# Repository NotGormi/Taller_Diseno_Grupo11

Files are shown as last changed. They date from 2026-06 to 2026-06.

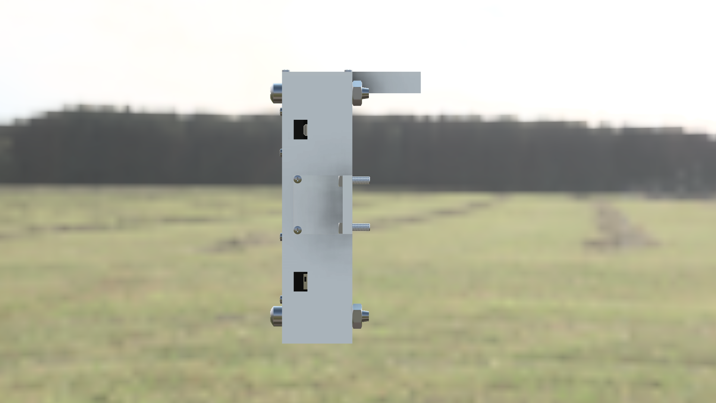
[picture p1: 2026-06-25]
diseno_3d/renders/03_isometrica_lateralD_v3.2.png

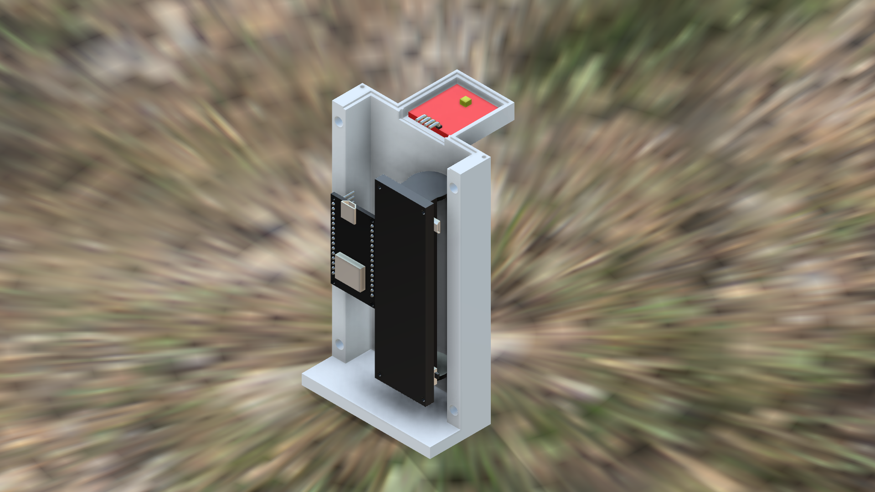
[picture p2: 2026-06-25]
diseno_3d/renders/05_componentes_expuestos_v3.2.png

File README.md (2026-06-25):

### Información del Equipo
- **Integrantes:**
  - Franco Coppellotti - Diseño 3D
  - Daniel Gormaz - Software
  - Vicente Molinos - Hardware
  
- **ODS Seleccionado:** ODS 3: Salud y bienestar
- **Problema a resolver:** Exposición inmedida al sol

### Descripción del Proyecto
Con la medición inmediata de rayos UV, se permite tomar accion para proteger la salud
de los estudiantes.

### Estado del Proyecto
- **Versión actual:** v3.0
- **Última actualización:** 24 de Junio, 2026
- **Estado:** Prototipo final

---

##  Estructura del Repositorio
```
├── hardware/          # Circuitos, esquemas y BOM
    ├── bom/
    ├── esquemas/
    └── fotos/
├── software/          # Código Arduino y librerías
    ├── docs/
    ├── librerias/
    └── src/
├── diseno_3d/        # Modelos Fusion 360 y renders
    ├── fusion360/
    ├── planos/
    └── renders/
├── testing/          # Validación con usuarios
    ├── datos/
    ├── evidencias/
    └── reportes/
├── documentacion/    # Reportes y presentación
    ├── presentacion/
    └── reporte_final/
└── iteraciones/      # Historial de versiones
    ├── iteracion_1/
    ├── iteracion_2/
    .
    .
    .
    └── iteracion_n/
```

---

##  Inicio Rápido

### Requisitos Previos
- Arduino IDE 2.3.8
- Fusion 360

### Instalación
1. Clonar el repositorio
2. Instalar librerías (ver `software/librerias/`)
3. Cargar código en ESP8266

---

##  Checklist de Entrega

### Hardware ✓
- [x] Esquema del circuito (Fritzing/Wokwi)
- [x] BOM completo
- [x] Fotos de alta resolución

### Software ✓
- [x] Código comentado
- [x] Librerías documentadas
- [x] Manual de instalación

### Diseño 3D ✓
- [x] Archivos Fusion 360 (.f3d) con TODOS los componentes
- [x] Renders de alta calidad (1+ ángulos)
- [x] Planos técnicos

### Testing ✓
- [ ] Reporte de testing con usuarios (mín. 5)
- [ ] Evidencias fotográficas/videos
- [ ] Datos cuantitativos

### Documentación ✓
- [x] Reporte final (máx. 15 páginas)
- [x] Presentación (10 min)

---

---

##  Licencia
Este proyecto es desarrollado como parte del curso TEI201 - Facultad de Ingenieria y Ciencias - Universidad Adolfo Ibañez

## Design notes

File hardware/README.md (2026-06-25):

# Hardware - Documentación

## Contenido
Esta carpeta contiene toda la documentación técnica del hardware del proyecto.

### 📁 Carpetas

#### `esquemas/`
Diagramas de circuitos y esquemáticos del sistema

#### `bom/`
Bill of Materials (Lista de materiales)

#### `fotos/`
Fotografías de alta resolución del prototipo ensamblado

---

## Instrucciones de Ensamble

### Componentes Principales
1. [ESP 8266] - Traducir los datos analógicos del sensor y mandarlos a una base de datos
2. [GUVA-S12SD] - Sensor que detecta radiación UV
3. [Shield and Battery 18650] - Alimentación eléctrica al circuito

### Pasos de Ensamblaje
1. Soldar los cables de GND y 3V en el battery shield
2. Afirmar los componentes ESP 8266 y el Shield a la cara posterior del encapsulado con pernos y tuercas
3. Afirmar el piso a la cara delantera del encapsulado con pegamento para plastico
4. Afirmar la cara delantera y posterior con tornillos o pernos y tuercas
5. Afirmar el techo a las dos caras con tornillos
6. Afirmar los enganches laterales a la cara posterior con 2 tornillos en cada enganche
7. Afirmar el encapsulado a una superficie con la ayuda de los 2 tornillos delanteros de los enganches, y la ayuda de 4 tornillos del cuerpo principal si fueron utilizados en el paso 4

### Precauciones
- ⚠️ Al soldar los cables al battery shield procurar que los estaños para cada cable no entren en contacto
- ⚠️ Procurar lijar bien cualquier superficie que sea impresa con soportes por la impresión 3d

---

## Especificaciones Técnicas

**Alimentación:** [3.3V y 3000 mAh]  
**Consumo:** [0.264Watts/80mA]  
**Dimensiones:** [148 mm x 71 mm x 139 mm]  
**Peso:** [417 gramos]

---

## Troubleshooting

| Problema | Posible Causa | Solución |
|---|---|---|
| Circuito no funciona | Contacto de estaño genera corto-circuito | Limpiar estaño y soldar sin que genere contacto |
| El encapsulado no encajan | Soportes por impresión 3d que ocupan espacio | Lijar la impresión en todas las secciones que tengan contacto con parte |

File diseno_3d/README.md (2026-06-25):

# Diseño 3D - Documentación

## ⚠️ REQUISITO CRÍTICO

El modelo 3D debe incluir **TODOS** los componentes del prototipo:
- ✅ Encapsulado exterior completo
- ✅ Placa ESP32/Arduino (con dimensiones exactas)
- ✅ Todos los sensores en posición de instalación
- ✅ Todos los actuadores
- ✅ Batería / fuente de alimentación
- ✅ Cableado (routing aproximado)
- ✅ Sistema de montaje (brackets, tornillos)
- ✅ Orificios de ventilación (si aplica)

**NO ES ACEPTABLE:** Solo el encapsulado vacío sin componentes internos

---

## Carpetas

#### `fusion360/`
Archivos nativos de Fusion 360 (.f3d)

#### `renders/`
Imágenes renderizadas de alta calidad

#### `planos/`
Planos técnicos con cotas

---

## Especificaciones

**Software:** Autodesk Fusion 360  
**Unidades:** Milímetros (mm)  
**Escala:** 1:1 (dimensiones reales)

**Dimensiones externas:** [148 mm × 71 mm × 139 mm]  
**Peso estimado:** [400 gramos]  
**Material:** [PLA]

---

## Consideraciones de Diseño

### Funcionales
- [x] Acceso a puertos USB/alimentación
- [x] Ventilación adecuada
- [x] Protección de componentes
- [x] Fácil acceso para mantenimiento
- [ ] Resistencia a condiciones ambientales

### Fabricación
- [x] Imprimible sin soportes excesivos
- [x] Tolerancias de ensamble (+0.2mm)
- [x] Grosor de pared mínimo 2mm
- [x] Sin ángulos imposibles (overhangs <45°)

---

## Configuración de Impresión 3D (si fue utilizada)

**Impresora:** Impresora 3D DEC UAI 
**Material:** [PLA]  
**Calidad de capa:** 0.2mm  
**Relleno:** 15%  
**Soportes:** [Sí] - En cada agujero, partes donde se ubica el sensor 
**Temperatura nozzle:** [°C] 200
**Temperatura cama:** [°C]  50
**Velocidad:** [45 mm/s]

**Tiempo estimado de impresión:** [18 horas]  
**Peso de material:** [230 gramos]

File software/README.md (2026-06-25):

# Software - Documentación

## Contenido
Esta carpeta contiene todo el código y documentación del software del proyecto.

### 📁 Carpetas

#### `src/`
Código fuente del proyecto (.ino para Arduino/ESP32)

#### `librerias/`
Librerías utilizadas en el proyecto

#### `docs/`
Documentación técnica del software

---

## Stack Tecnológico

**Plataforma:** Arduino / ESP32  
**Lenguaje:** C/C++  
**IDE:** Arduino IDE 2.3.8  
**Librerías principales:**
- ESP8266WiFi.h - Versión 1.0
- FirebaseClient.h - Versión 2.2.9
---

## Instalación y Configuración

### 1. Instalar Arduino IDE
1. Instalar Arduino IDE desde la página `https://docs.arduino.cc/software/ide/`

### 2. Configurar ESP8266
1. Descargar el driver universal CP210x desde la página `https://www.silabs.com/software-and-tools/usb-to-uart-bridge-vcp-drivers?tab=downloads`
2. Extraer el archivo zip en una carpeta destinada por el usuario (por ejemplo una carpeta en el escritorio llamada `Driver CP2102`)
3. En Arduino IDE, ir a `File > Preferences > Settings` y colocar en `Additional boards manager URLs:` colocar `https://arduino.esp8266.com/stable/package_esp8266com_index.json`

### 3. Cargar Código
1. Abrir `src/SensorUV_G11.ino`
2. Seleccionar placa y puerto
3. Compilar y subir

---

## Configuración de Parámetros

Editar las siguientes constantes en el código:

```cpp
// WiFi
const char* ssid "tu_red"
const char* password "tu_password"
```

---

### Módulos Principales
1. **Inicialización** - Setup del sistema
2. **Lectura de Sensores** - Captura de datos
3. **Procesamiento** - Análisis y decisiones
4. **Comunicación** - Envío de datos

---

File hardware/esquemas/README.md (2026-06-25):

# Esquemas de Circuito

## Archivos Requeridos

### Formato Fritzing
- `circuito_completo.fzz` - Archivo fuente Fritzing
- `esquema_circuito.png` - Exportación del esquema
- `pcb_layout.png` - (opcional) Layout de PCB

### Formato Wokwi
- `wokwi_diagram.json` - Archivo de proyecto Wokwi
- `wokwi_screenshot.png` - Captura del circuito
- `wokwi_link.txt` - URL del proyecto online

---

## Nomenclatura de Archivos
- Usar nombres descriptivos
- Incluir versión: `v3_esquema_final.fzz`
- Fecha en formato: `YYYYMMDD_descripcion`

---

## Notas de Diseño
[Explicar decisiones importantes de diseño del circuito]
Conexiones 
Sensor - Placa
S - A0 (Lectura de datos analógicos)
VCG - 3v3 (Alimentación eléctrica)
GND - GND

Shield - Placa
3V - 3v3 (Alimentación eléctrica)
GND - GND

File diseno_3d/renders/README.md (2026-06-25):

# Renders de Alta Calidad

## Renders Requeridos (Mínimo 4 ángulos)

### 1. Vista Isométrica Frontal
`01_isometrica_frontal.png`
- Muestra exterior completo
- Iluminación clara
- Resolución: 1920×1080 mínimo

### Renders Opcionales (Recomendados)
- `02_detalle_sensores.png` - Close-up de sensores
- `03_ensamble_explosionado.png` - Componentes separados
- `04_variantes_color.png` - Si hay opciones de diseño

---

## Configuración de Render en Fusion 360

### Settings Recomendados
- **Render Engine:** Local / Cloud
- **Environment:** [Tipo de iluminación]
- **Resolution:** 1920×1080 o superior
- **Quality:** High
- **Exposure:** [Ajustado para visibilidad]
- **Effects:** Ambient Occlusion ON

### Materiales y Apariencias
Asignar materiales realistas:
- Plástico: PLA/ABS mate o satinado
- Electrónica: PCB verde, componentes negros
- Metales: Tornillos acero inoxidable

---

## Nomenclatura de Archivos
```
[numero]_[descripcion]_[version].png

Ejemplo:
01_isometrica_frontal_v3.png
```

---

## Checklist de Calidad

- [x] Resolución mínima 1920×1080
- [x] Formato PNG (con transparencia si aplica)
- [x] Iluminación sin sombras excesivas
- [x] Componentes internos visibles en corte
- [x] Fondo neutro o contextual apropiado
- [ ] Sin aliasing o bordes pixelados
- [ ] Todos los componentes críticos visibles

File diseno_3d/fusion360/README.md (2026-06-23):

# Archivos Fusion 360

## Archivos Requeridos

### `modelo_completo_v3.f3d`
Archivo principal con **historial de cambios completo**

**DEBE INCLUIR:**
-  Todos los componentes modelados
-  Ensamble completo funcional
-  Historial de diseño (timeline)
-  Materiales asignados
-  Constraints y relaciones

---

## Estructura del Modelo

### Componentes (Components)
```
Ensamble_Principal
├── Encapsulado_Lateral
├── Encapsulado_Inferior
├── Encapsulado_Superior
├── Soporte_Bateria
├── Bracket_Montaje
└── Tornilleria
```

### Uniones (Joints)
Documentar las juntas principales y sus restricciones

### Parámetros
Listar parámetros principales utilizados:
- `ancho_total = 146mm`
- `largo_total = 71mm`
- `alto_total = 139mm`
- `grosor_pared = 3mm`

---

## Instrucciones de Apertura

1. Abrir Fusion 360
2. File > Open > Seleccionar archivo `.f3d`
3. Verificar que todas las referencias están cargadas
4. Revisar timeline para ver historial

---

## Versiones

| Versión | Fecha | Cambios Principales |
|---|---|---|
| v3.2 | [15/06] | Versión final para Avance #3 |
| v3.0 | [11/06] | Diseño final para avance #3 |
| v2.0 | [29/04] | Ajustes post Avance #2 |
| v1.0 | [27/04] | Primera versión funcional |

---

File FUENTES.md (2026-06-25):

# Fuentes del proyecto

## Librerías utilizadas

| Librería | Versión | Uso en el proyecto |
|---|---|---|
| ESP8266WiFi | 1.0 | Creación de servidor web |
|  FirebaseClient | 2.2.9 | Almacenamiento de datos |

## Uso de Inteligencia Artificial

- Herramienta: ClaudeAI Sonnet 4.6 (mayo 2026)
- Prompt: "Generame un código para Arduino IDE, conectando un sensor GUVA-S12SD
a una placa de desarrollo NodeMCU ESP8266."
- Adaptación: Promedio de 10 muestras de voltaje del sensor UV, información
otorgada por las mediciones.
- Comprensión:

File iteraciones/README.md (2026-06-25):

# Historial de Iteraciones

## Propósito

Esta carpeta documenta la evolución del prototipo a través de las diferentes versiones desarrolladas durante el curso.

**CRÍTICO:** Demostrar el proceso iterativo es un requisito para obtener puntaje completo en "Integración y Refinamiento" (2.5 puntos).

---

## Estructura de Carpetas

Cada iteración tiene su propia carpeta con documentación de esa versión:

```
iteraciones/
├── iteracion_1/    # Concepto inicial - Prototipo alpha
├── iteracion_2/    # Primera iteración - Avance #2
└── iteracion_3/    # Versión final - Avance #3
```

---

## Contenido de Cada Iteración

Cada carpeta debe incluir:

1. **README.md** - Descripción de la versión
2. **Fotos** - Imágenes del prototipo en ese estado
3. **Esquema** - Circuito de esa versión (si cambió)
4. **Código** - Versión del software (si cambió)
5. **Notas** - Problemas identificados y mejoras planificadas

---

## Tabla Comparativa de Iteraciones

| Aspecto | v1 | v2 | v3 |
|---|----|----|----|
| **Fecha** | 23/04/2026 | 21/05/2026 | 24/06/2026 |
| **Sensores** | GUVA-S12SD | GUVA-S12SD | GUVA-S12SD |
| **Actuadores** | ❌ | ❌ | ❌ |
| **Conectividad** | Local | Inalambrica | Base de Datos (nube) |
| **Encapsulado** | Conceptual | Prototipo | Finalizado |
| **Testing** | Solo toma de datos | Servidor Locar | Base de datos |
| **Funcionalidad** | 40% | 75% | 100% |

---

## Evolución del Diseño

### Versión 1 (Iteración 1) - Concepto Inicial
**Fecha:** [23/04/2025]  
**Estado:** Prototipo alpha - Prueba de concepto

**Características:**
- Diseño conceptual de encapsulado y codigo inicial
- Problemas principales identificados: | Diseño sin mediciones | Diseño solo funcional | No hay orden de componentes | Codigo solo cumple con toma de datos |
- Aprendizajes clave: | Importancia de diseño y codigo ordenado y completo |

### Versión 2 (Iteración 2) - Primera Mejora
**Fecha:** [30/04/2025]  
**Estado:** Prototipo funcional mejorado

**Mejoras implementadas:**
- [Mejora 1] Diseño con medicioens y espacios para cada componente
- [Mejora 2] Codigo permite guardar datos

**Problemas pendientes:**
- [Problema 1] El diseño no cumple en contexto de situacion real
- [Problema 2] El codigo no permite ver información desde cualquier dispositivo

### Versión 3.0 (Iteración 3) - Versión Semi Completa
**Fecha:** [11/06/2025]  
**Estado:** Prototipo con diseño final

**Mejoras finales:**
- [Mejora 1] Diseño cumple con un proposito real
- [Mejora 2] Codigo permite visualizar datos desde un servidor

  **Problemas pendientes:**
- [Problema 1] El diseño no cumple con sistema de fijación

### Versión 3.2 (Iteración 4) - Versión FInal
**Fecha:** [21/06/2025]  
**Estado:** Prototipo final y robusto

**Mejoras finales:**
- [Mejora 1] Diseño puede ser fijado y mantenido en contexto de situación real

**Resultado:**
- Sistema robusto y probado
- Listo para piloto en terreno

---

## Justificación de Cambios

### Hardware
**De v1 a v2:**
- Cambio: Uso de shield y bateria para alimentar el microcontrolador
- Razón: En caso real, el microcontrolador no estara conectaddo a una computadora que pudiera enviara energia
- Impacto: Diseño mas portatil y general, que permite tomar mediciones desde lugares mas amplios

**De v2 a v3:**
- Cambio: Quitar el protoboard
- Razón: Habilidad de poder utilizar los pines del microcontrolador sin necesitar de un repetidor
- Impacto: Diseño con mas espacio y mas ligero lo que equivale a un menor costo de fabricación

### Software
**De v1 a v2:**
- El prototipo ermite lectura de datos en un servidor locar

**De v2 a v3:**
- El prototipo guarda datos en una base de datos

### Diseño 3D
**De v1 a v2:**
- Cambio de material utilizado y espació para componentes con mediciones

**De v2 a v3:**
- Cambio de caja a L y sistema de fijación

---

## Incorporación de Feedback

### Feedback del Avance #1 → Cambios en v2
1. El encapsulado es basico
2. El codigo no permite recopilar datos
   - Acción tomada: Aplicación de materiales en el diseño y guardado de datos por el codigo

### Feedback del Avance #2 → Cambios en v3
1. El encapsulado no puede ser fijado a una pared
2. El codigo no permite visualizar datos desde un sevidor
   - Acción tomada: Cambio de diseño desde una caja a una letra "L" invertida con ranuras a los costados para atornillar e inclusión de servidor para lectura de datos

### Feedback de Usuarios → Cambios en v3
1. El encapsulado no permite una ranura donde solo ilumine al sensor y no al resto de componentes
   - Acción tomada: Cambio de diseño del encapsulado superior hacia una tapa con una pequeña ranura solo para el sensor

---

## Métricas de Mejora

| Métrica | v1 | v2 | v3 | Mejora Total |
|---|----|----|----| ---|
| Tiempo respuesta (ms) | 500 | 200 | 100 | ↓80% |
| Consumo (mA) | 250 | 180 | 120 | ↓52% |
| Tasa de errores (%) | 15 | 5 | 1 | ↓93% |
| Toma de datos (1-5) | 3.0 | 3.8 | 4.5 | ↑50% |

---

## Lecciones Aprendidas

### Técnicas
- Modelaje 3D en Autodesk Fusion
- Escritura de codigo para microcontrolador ESP8266

### De Proceso
- Evaluación critica del proyecto al momento de buscar fallos en el diseño y codigo
- Asignar recursos a cada integrante para avanzar de forma eficaz y equitativa el proyecto

### De Trabajo en Equipo
- Comunicación: Poder dar opiniones y escuchar las demas al momento de querer mejorar el proyecto 
- Compromiso: Poder tomar conciencia e iniciativa al querer hacer el proyecto no solo por requerimiento

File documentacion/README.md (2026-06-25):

# Documentación del Proyecto

## Contenido

Esta carpeta contiene la documentación final del proyecto para la entrega del Avance #3.

---

##  Carpetas

#### `reporte_final/`
Reporte completo del proyecto (máximo 15 páginas)

#### `presentacion/`
Slides de la presentación final

---

## Documentos Principales

### 1. Reporte Final del Proyecto
`reporte_final_v3.pdf`

Máximo 15 páginas, formato profesional

### 2. Presentación Final
`presentacion_avance3.pdf` o `.pptx`

Duración: 10 minutos de presentación

---

## Checklist de Entrega

### Documentos Obligatorios
- [ ] Reporte final PDF (máx. 15 páginas)
- [x] Presentación PDF/PPTX
- [ ] Manual de usuario (puede estar integrado en reporte)

### Contenido del Reporte
- [ ] Contexto y problemática ODS
- [ ] Solución propuesta (descripción técnica)
- [ ] Proceso de diseño e iteraciones
- [ ] Documentación técnica (resumen)
- [ ] Resultados de testing y validación
- [ ] Análisis de impacto ODS
- [ ] Conclusiones y trabajo futuro
- [ ] Referencias bibliográficas

### Contenido de Presentación
- [x] Problema y contexto ODS (2 min)
- [x] Solución técnica (3 min)
- [x] Iteraciones y refinamiento (2 min)
- [ ] Validación con usuarios (2 min)
- [x] Demo en vivo (3 min)
- [x] Conclusiones (1 min)

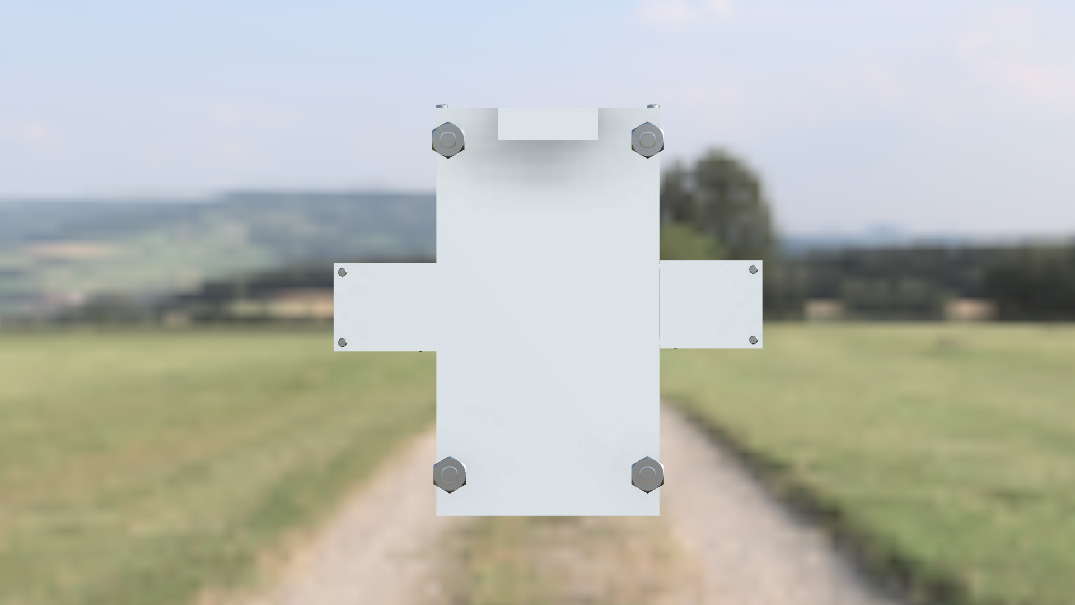
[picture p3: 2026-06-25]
diseno_3d/renders/02_isometrica_frontal_v3.2.png

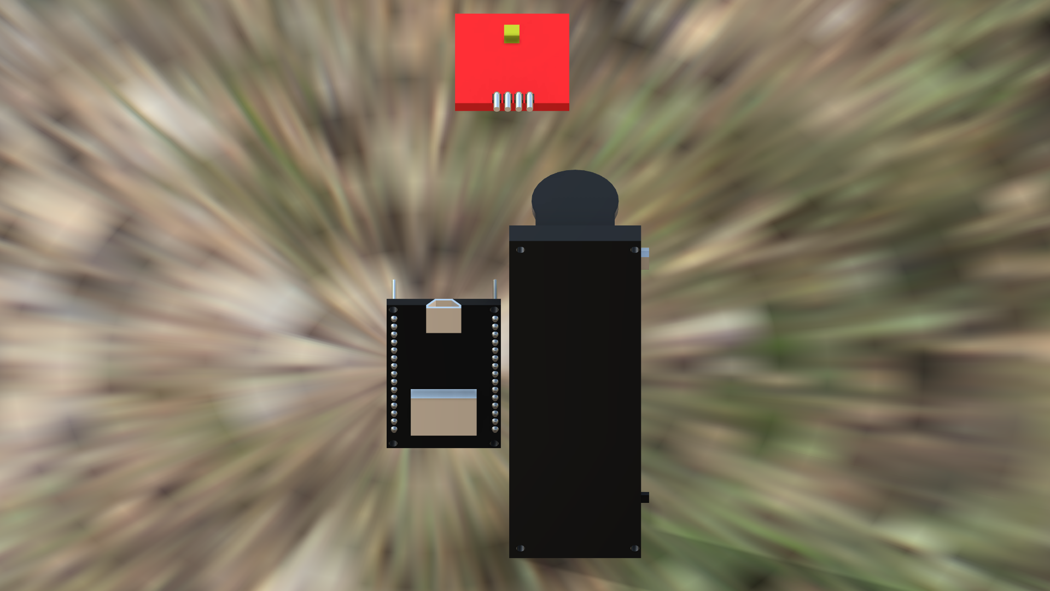
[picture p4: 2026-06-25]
diseno_3d/renders/07_electronicos_expuestos_v3.2.png

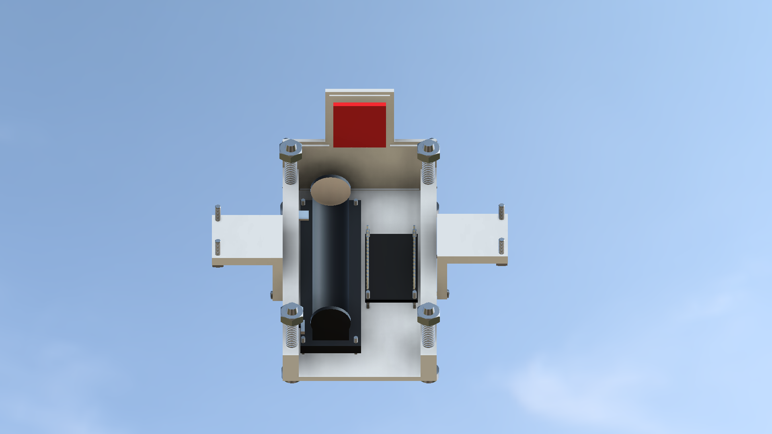
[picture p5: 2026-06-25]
diseno_3d/renders/06_frontal_inferior_fijaciones_v3.2.png

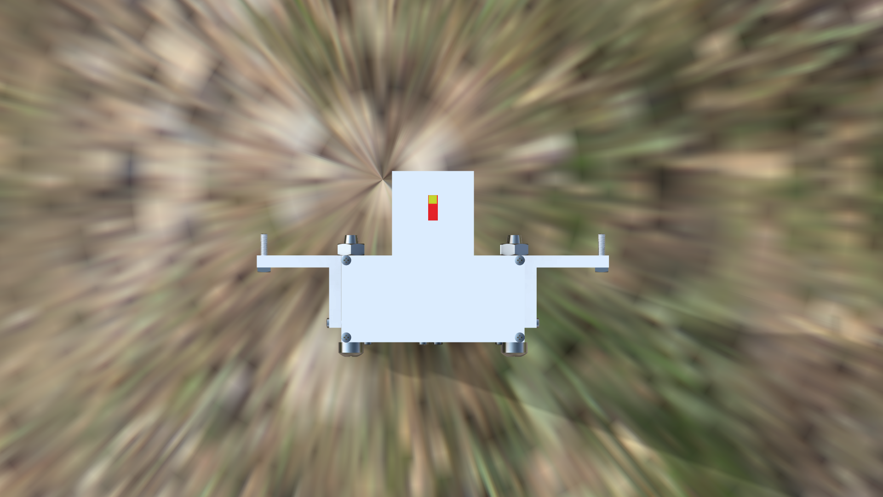
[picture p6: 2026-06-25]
diseno_3d/renders/04_isometrica_superior_v3.2.png

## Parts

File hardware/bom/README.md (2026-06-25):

# Bill of Materials (BOM)

## Formato del Archivo

El archivo BOM debe incluir las siguientes columnas:

| Columna | Descripción | Ejemplo |
|---|---|---|
| Cantidad | Número de unidades | 1 |
| Componente | Nombre descriptivo | ESP32 DevKit V1 |
| Especificación | Detalles técnicos | 30 pines, WiFi+BT |
| Fabricante | Marca del componente | Espressif |
| Código/SKU | Identificador único | ESP32-WROOM-32 |
| Proveedor | Tienda/distribuidor | AliExpress, MercadoLibre |
| Precio Unitario | Costo por unidad (CLP) | $8,990 |
| Precio Total | Cantidad × Precio | $8,990 |
| Datasheet | Link a especificaciones | [URL] |

---

## Archivos a Incluir

- `bom_completo.xlsx` - Lista completa de materiales
- `bom_completo.pdf` - Versión PDF para visualización
- `datasheets/` - Carpeta con PDFs de componentes críticos

---

## Presupuesto Total

**Costo Total Estimado:** $[24471] CLP

### Desglose por Categoría
- Microcontrolador: $7,190
- Sensores: $4,290
- Actuadores: $0,000
- Estructura/Encapsulado: $5,493
- Otros: $7,498

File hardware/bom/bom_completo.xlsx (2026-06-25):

Componente | Cantidad | Especificaciónes | Precio Unitario | Precio Total Componente | Proveedor | Datasheet | Fabricante | Codigo | Precio Total
ESP-8266 | 1 | Nodemcu Wifi Lolin V3 | 7190 | 7190 | Mercadolibre | https://www.mercadolibre.cl/modulo-wifi-nodemcu-v3-esp8266esp12e/p/MLC2077417980 | Genérica |  | 24471.707
GUVA-S12SD | 1 | GUVA-S12SD 3528 | 4290 | 4290 | Mercadolibre | https://www.mercadolibre.cl/sensor-uv-guva-s12sd-3528-intensidad-ultravioleta-p-arduino/p/MLC2078122772 | Genérica
Battery Shield 18650 | 1 | V3 | 3.107 | 3.107 | AliExpress | https://es.aliexpress.com/item/1005009568944646.html?curPageLogUid=3lWbllUl6yrP | WorldChips
Battery 18650 | 1 | 3000 mAh | 14.990/2 | 7495 | Sodimac | https://www.sodimac.cl/sodimac-cl/articulo/147430586/Baterias-Pack-x2-Pilas-18650-3000mah-Verde/147430587 | Generico | 147430587
Tornillos 4 x 1/2" | 8 | Acero | 137 | 1380 | Sodimac | https://www.sodimac.cl/sodimac-cl/articulo/112857399/Tornillo-Tirafondo-Madera-1-2-2.8-mm-4-unidad(es)/112857400 | Mamut | 112857400
Pernos M3 x 8 | 4 | Perno Parker | 323 | 1290 | Sodimac | https://www.sodimac.cl/sodimac-cl/articulo/112740533/Perno-cabeza-boton-M3-x-8-mm-c-tuerca-pavonado-negro-4u/112740535 | Mamut | 112740535
Pernos M4 x 12 c/tuerca | 4 | Perno Parker | 563 | 2252 | Sodimac | https://www.sodimac.cl/sodimac-cl/articulo/112744129/Perno-cabeza-boton-M4-x-12-mm-c-tuerca-pavonado-negro-3u/112744130 | Mamut | 112744130
Tornillo 12x 3" | 4 | Metal | 0.1429 | 571.6 | Sodimac | https://www.sodimac.cl/sodimac-cl/articulo/146215141/tornillo-autoperforante-metal-3-12-100-unidades/146215142 | Mamut | 146215142

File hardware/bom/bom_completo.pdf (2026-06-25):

Componente | Cantidad | Especificaciónes | Precio Unitario

Precio Total
Componente | Proveedor | Datasheet | Fabricante | Codigo | Precio Total
ESP-8266 | 1

Nodemcu Wifi Lolin
V3 | 7190 | 7190 Mercadolibre | https://www.mercadolibre.cl/modulo-wifi-nodemcu-v3-esp8266esp12e/p/MLC2077417980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 Genérica | 24471.707
GUVA-S12SD | 1 GUVA-S12SD 3528 | 4290 | 4290 Mercadolibre | https://www.mercadolibre.cl/sensor-uv-guva-s12sd-3528-intensidad-ultravioleta-p-arduino/p/MLC2078122772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 Genérica
Battery Shield
18650 | 1 V3 | 3.107 | 3.107 AliExpress | https://es.aliexpress.com/item/1005009568944646.html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 WorldChips
Battery 18650 | 1 3000 mAh | 14.990/2 | 7495 Sodimac | https://www.sodimac.cl/sodimac-cl/articulo/147430586/Baterias-Pack-x2-Pilas-18650-3000mah-Verde/147430587 Generico | 147430587
Tornillos 4 x
1/2" | 8 Acero | 137 | 1380 Sodimac | https://www.sodimac.cl/sodimac-cl/articulo/112857399/Tornillo-Tirafondo-Madera-1-2-2.8-mm-4-unidad(es)/112857400 Mamut | 112857400
Pernos M3 x 8 | 4 Perno Parker | 323 | 1290 Sodimac | https://www.sodimac.cl/sodimac-cl/articulo/112740533/Perno-cabeza-boton-M3-x-8-mm-c-tuerca-pavonado-negro-4u/112740535 Mamut | 112740535
Pernos M4 x 12
c/tuerca | 4 Perno Parker | 563 | 2252 Sodimac | https://www.sodimac.cl/sodimac-cl/articulo/112744129/Perno-cabeza-boton-M4-x-12-mm-c-tuerca-pavonado-negro-3u/112744130 Mamut | 112744130
Tornillo 12x 3" | 4 Metal | 0.1429 | 571.6 Sodimac | https://www.sodimac.cl/sodimac-cl/articulo/146215141/tornillo-autoperforante-metal-3-12-100-unidades/146215142 Mamut | 146215142

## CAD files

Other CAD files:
diseno_3d/fusion360/modelo_completo_v3.2.f3z
iteraciones/iteracion_1/modelo_v1.f3d
iteraciones/iteracion_2/modelo_v2.f3d
iteraciones/iteracion_3/modelo_v3.f3z

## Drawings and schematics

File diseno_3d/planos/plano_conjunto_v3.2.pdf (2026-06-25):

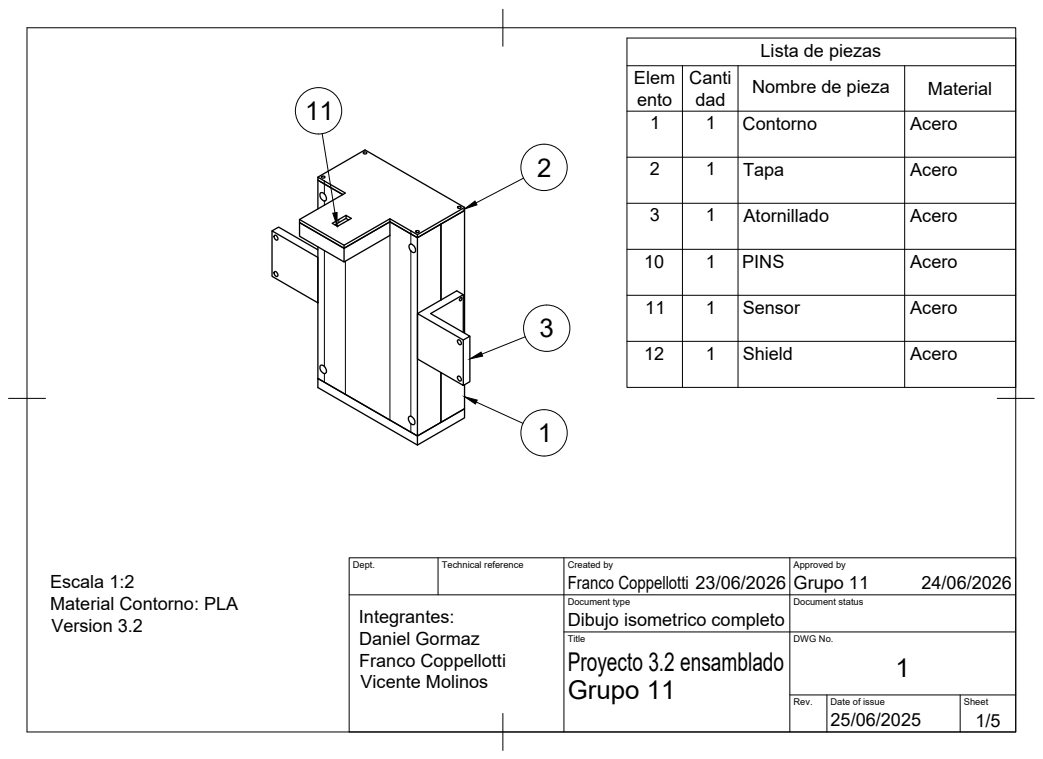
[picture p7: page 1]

Lista de piezas

Elem ento | Canti dad | Nombre de pieza | Material

1 | 1 | Contorno | Acero

2 | 1 | Tapa | Acero

3 | 1 | Atornillado | Acero

10 | 1 | PINS | Acero

11 | 1 | Sensor | Acero

12 | 1 | Shield | Acero

Dept. | Technical reference | Created by Franco Coppellotti 23/06/2026 | Approved by Grupo 11 24/06/2026

Escala 1:2
Material Contorno: PLA
Version 3.2

Integrantes: Daniel Gormaz Franco Coppellotti Vicente Molinos | | Document type Dibujo isometrico completo | Document status

Title Proyecto 3.2 ensamblado Grupo 11 | DWG No. 1

Rev. | Date of issue | Sheet

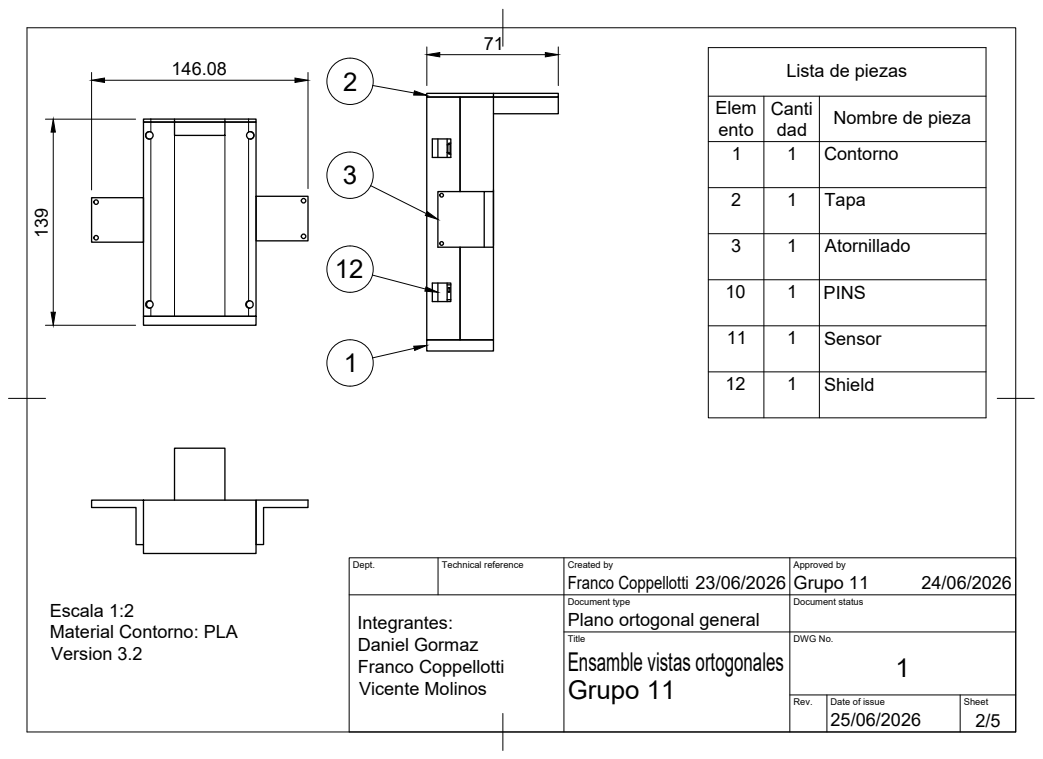
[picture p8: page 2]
Shield 139

Lista de piezas

Elem ento | Canti dad | Nombre de pieza

1 | 1 | Contorno

2 | 1 | Tapa

3 | 1 | Atornillado

10 | 1 | PINS

11 | 1 | Sensor

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

Integrantes: Daniel Gormaz Franco Coppellotti Vicente Molinos | | Document type Plano ortogonal general | Document status

Escala 1:2
Material Contorno: PLA
Version 3.2

Title Ensamble vistas ortogonales Grupo 11 | DWG No. 1

Rev. | Date of issue | Sheet

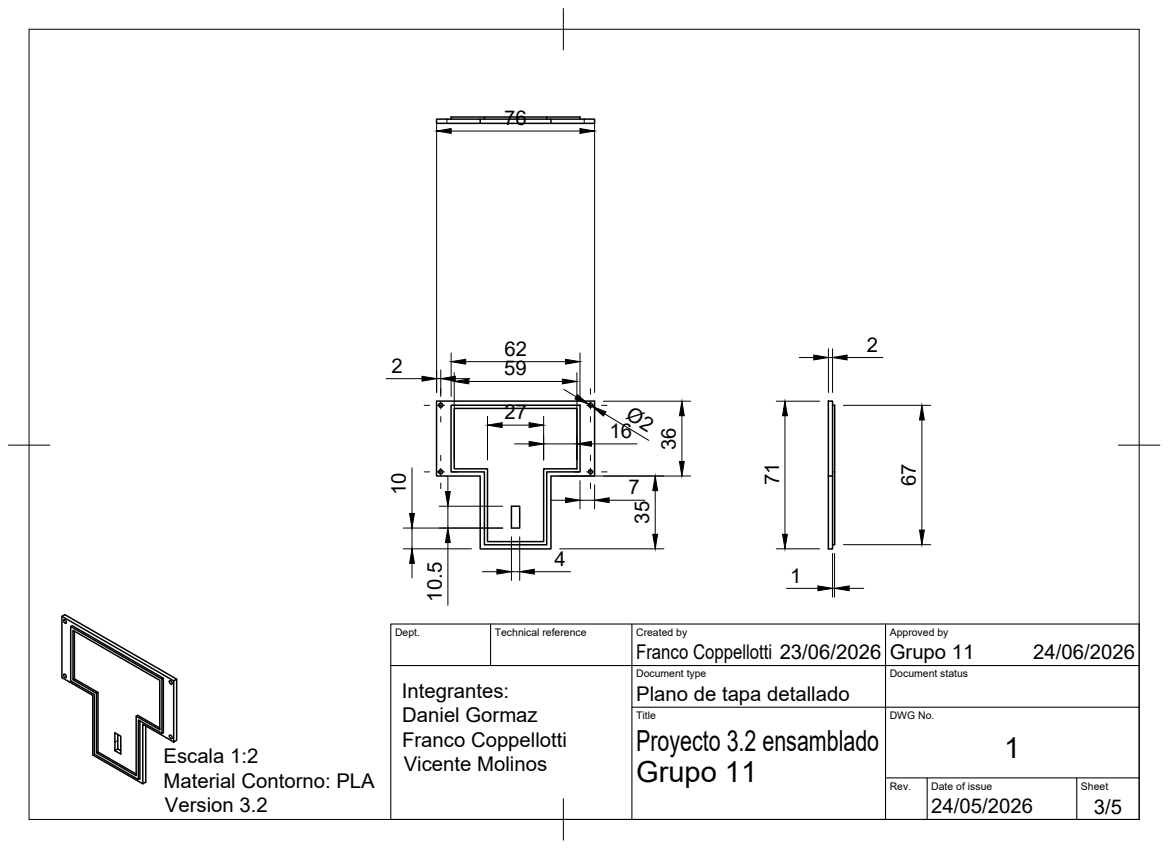
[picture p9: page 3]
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

Integrantes: Daniel Gormaz Franco Coppellotti | | Document type Plano de tapa detallado | Document status

Title Proyecto 3.2 ensamblado Grupo 11 | DWG No. 1

Vicente Molinos Escala 1:2
Material Contorno: PLA
Version 3.2

Rev. | Date of issue | Sheet

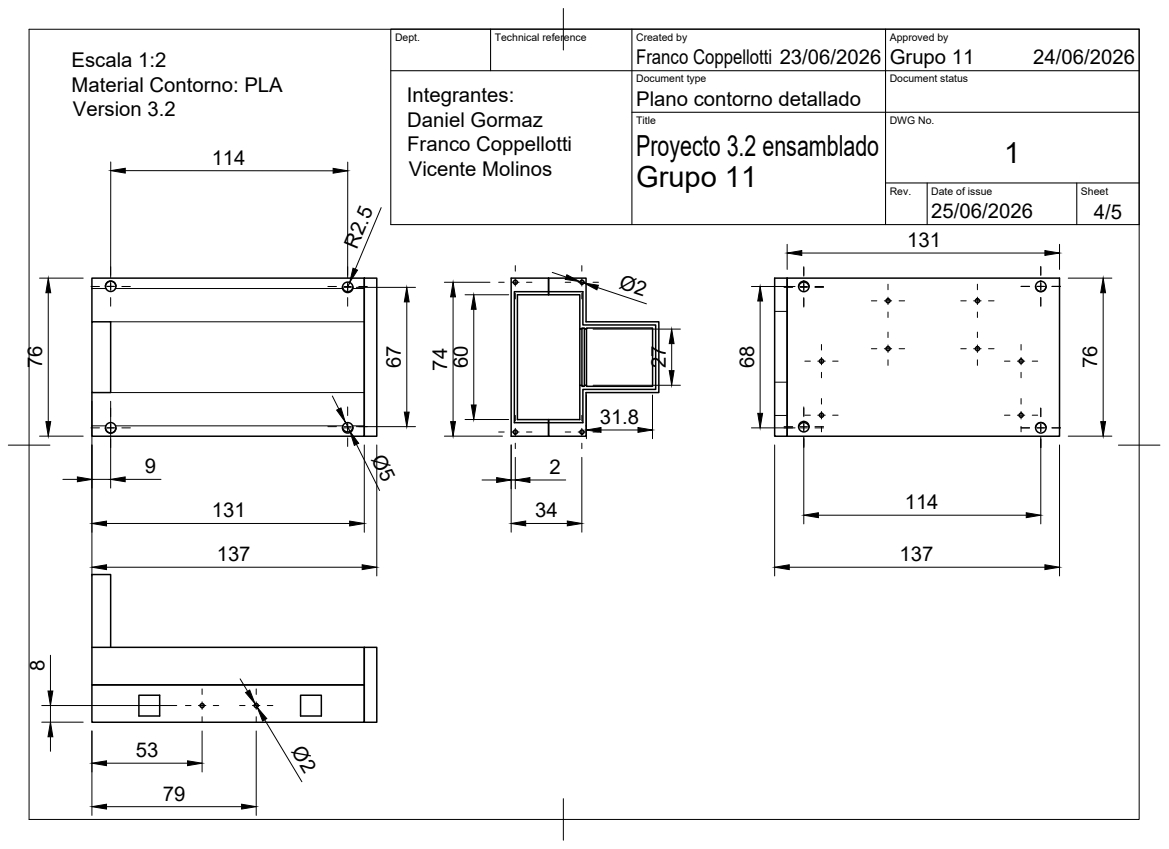
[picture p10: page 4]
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

Escala 1:2
Material Contorno: PLA
Version 3.2

Integrantes: Daniel Gormaz Franco Coppellotti Vicente Molinos | | | Document type Plano contorno detallado | Document status

Title Proyecto 3.2 ensamblado Grupo 11 | DWG No. 1

Rev. | Date of issue 25/06/2026 | Sheet 4/5

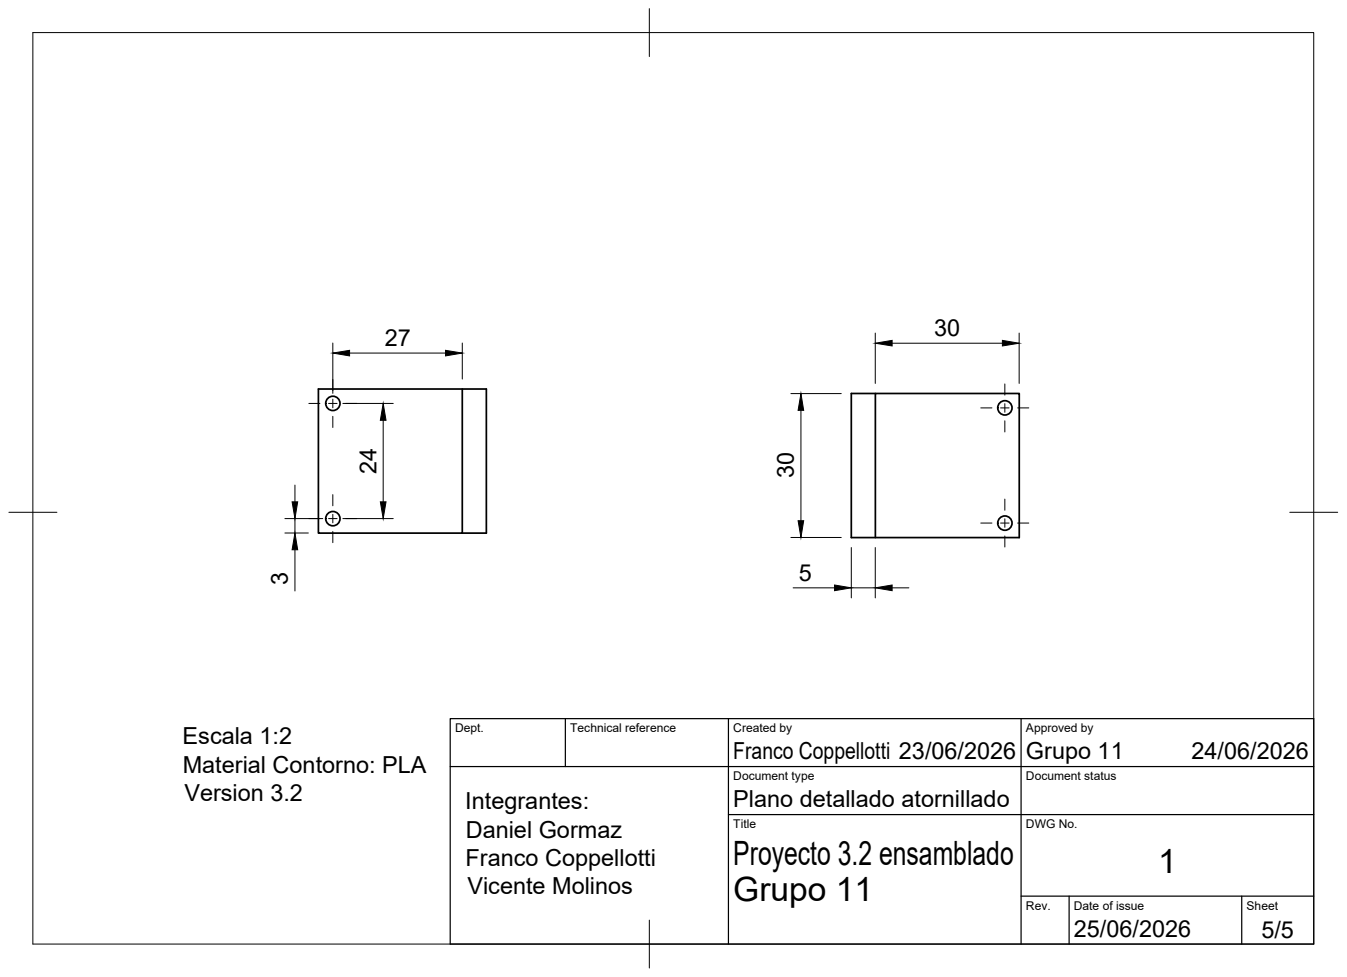
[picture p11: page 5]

Escala 1:2
Material Contorno: PLA
Version 3.2

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

Integrantes: Daniel Gormaz Franco Coppellotti Vicente Molinos | | Document type Plano detallado atornillado | Document status

Title Proyecto 3.2 ensamblado Grupo 11 | DWG No. 1

Rev. | Date of issue | Sheet

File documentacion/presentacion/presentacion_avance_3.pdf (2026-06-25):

## Campus shield

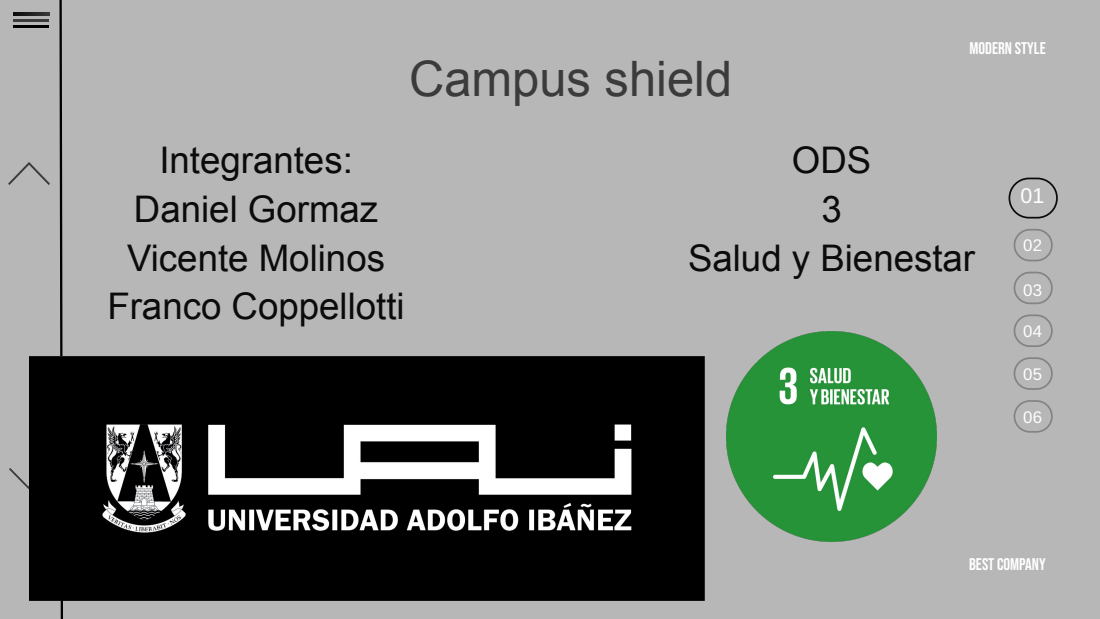
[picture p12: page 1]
MODERN STYLE; BEST COMPANY; Integrantes: Daniel Gormaz Vicente Molinos Franco Coppellotti; ODS 3 Salud y Bienestar

## Problemática ODS

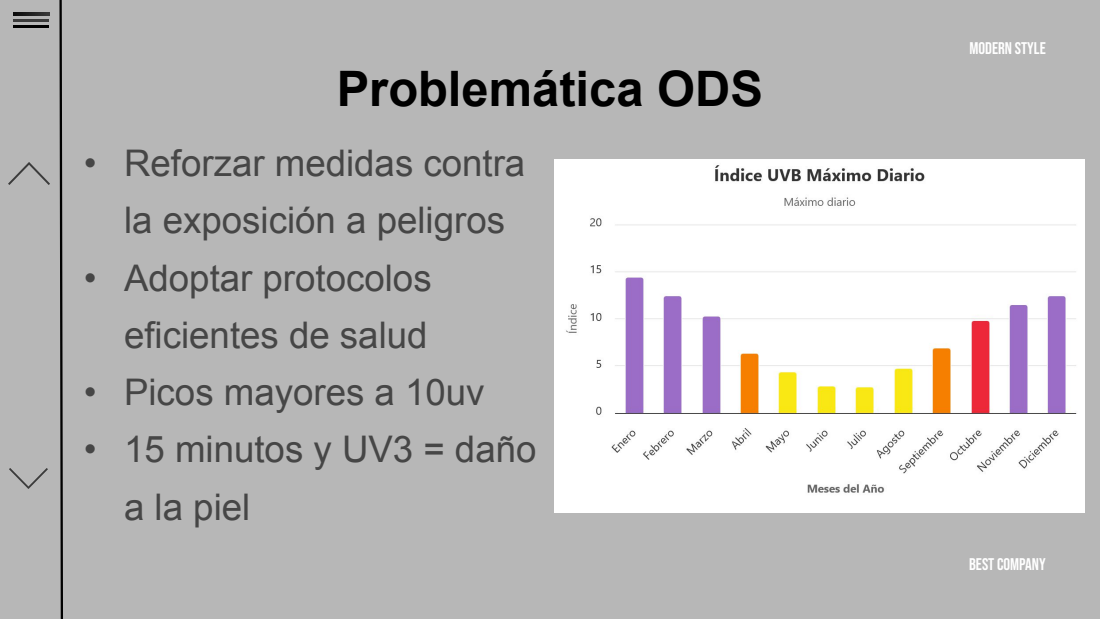
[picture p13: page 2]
MODERN STYLE; BEST COMPANY

• Reforzar medidas contra
la exposición a peligros
• Adoptar protocolos
eficientes de salud
• Picos mayores a 10uv
• 15 minutos y UV3 = daño
a la piel

## Problema Específico

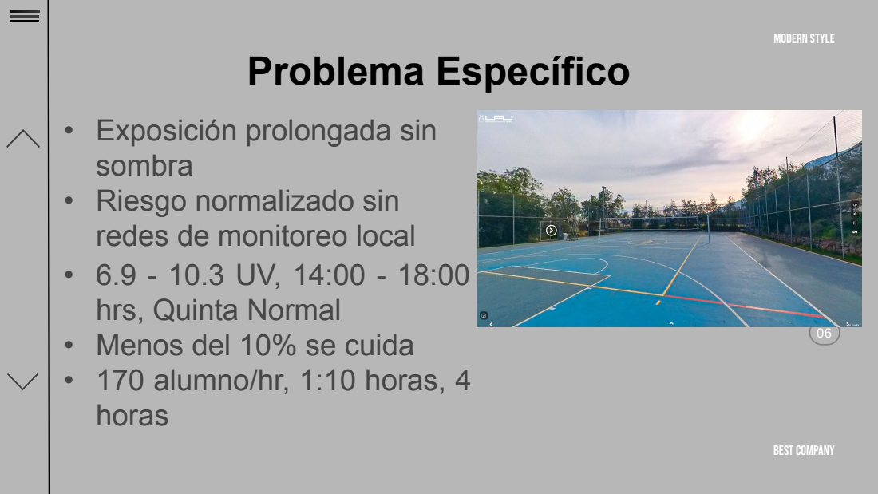
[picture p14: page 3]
MODERN STYLE; BEST COMPANY

• Exposición prolongada sin
sombra
• Riesgo normalizado sin
redes de monitoreo local
hrs, Quinta Normal
• Menos del 10% se cuida
• 170 alumno/hr, 1:10 horas, 4
horas

## Arquitectura

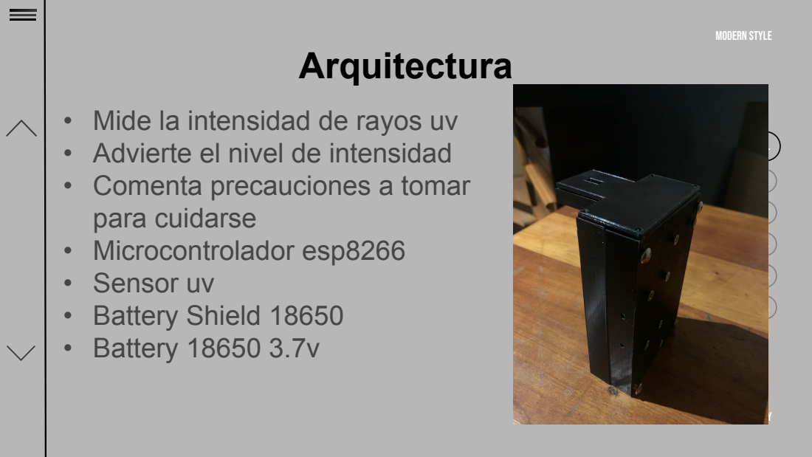
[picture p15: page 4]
MODERN STYLE; BEST COMPANY

• Mide la intensidad de rayos uv
• Advierte el nivel de intensidad
• Comenta precauciones a tomar
para cuidarse
• Microcontrolador esp8266
• Sensor uv
• Battery Shield 18650
• Battery 18650 3.7v

01

02

03

04

05

06

MODERN STYLE

BEST COMPANY

# "Demo en vivo"

## Software y Diseño 3D

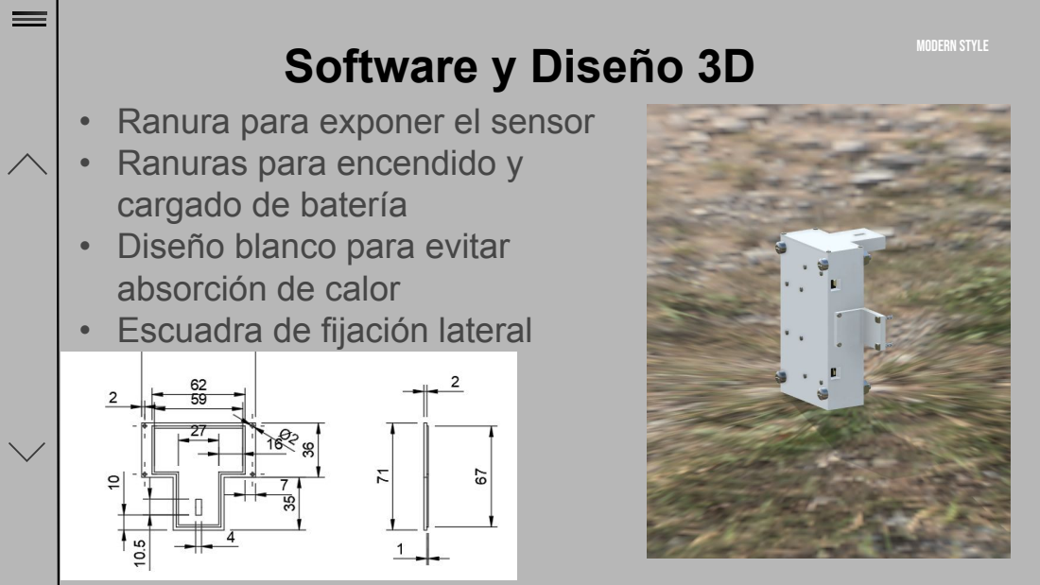
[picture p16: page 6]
MODERN STYLE; BEST COMPANY

• Ranura para exponer el sensor
• Ranuras para encendido y
cargado de batería
• Diseño blanco para evitar
absorción de calor
• Escuadra de fijación lateral

## Evolución del

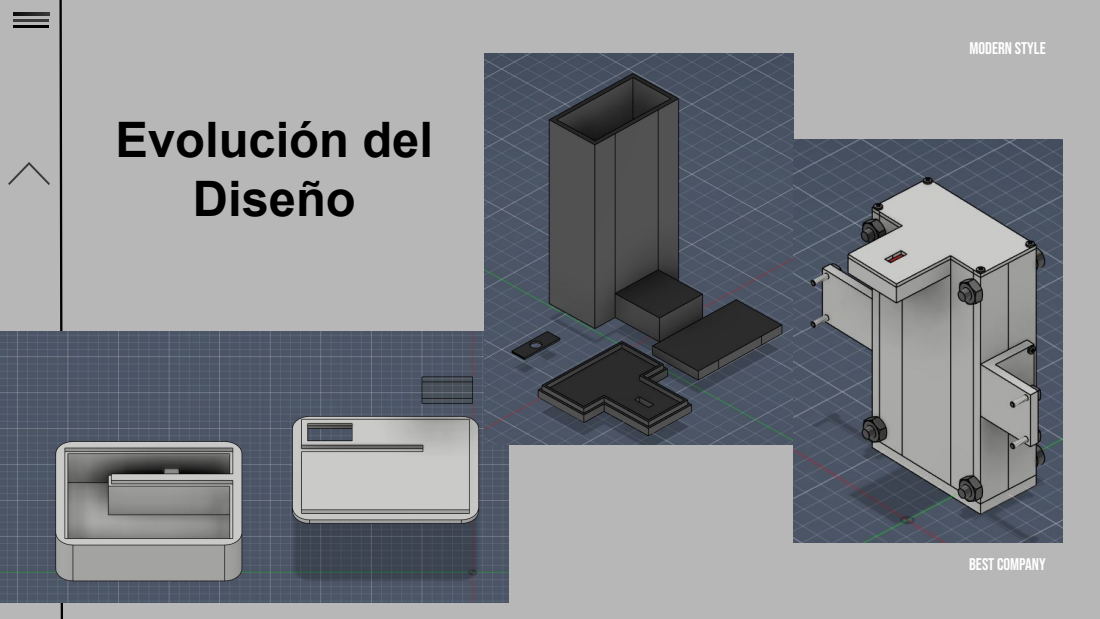
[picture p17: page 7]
MODERN STYLE; BEST COMPANY; Diseño

## Resultados e Impacto ODS

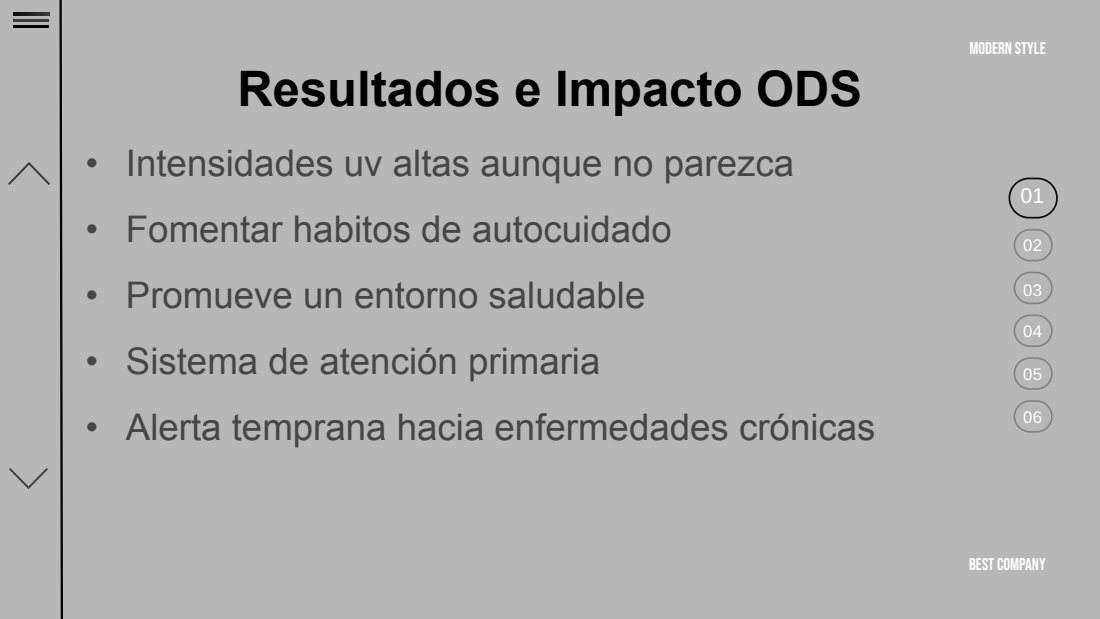
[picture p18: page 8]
MODERN STYLE; BEST COMPANY

• Intensidades uv altas aunque no parezca

• Fomentar habitos de autocuidado

• Promueve un entorno saludable

• Sistema de atención primaria

• Alerta temprana hacia enfermedades crónicas

## Conclusiones

MODERN STYLE; BEST COMPANY

• Medir y advertir intensidades altas

• Permite tomar mediciones de
precaución

• Es necesario un ejercicio humano
• Tomar conciencia no es suficiente

• Fragil a cambios climaticos

## Trabajo Futuro

MODERN STYLE; BEST COMPANY

• Sensores de confort termico, humedad y temperatura

• Aplicación móvil con recordatorios de aplicación

• Tiempo máximo seguro de exposición

• Alertas físicas como leds

• Mapeo de puntos seguros en el campus

01

02

03

04

05

06

MODERN STYLE

BEST COMPANY

# Preguntas

01 (https://climatologia.meteochile.gob.cl/application/mensual/indiceUvbMaximoMensual/330020/2025/3)

02

03

04

05

06

MODERN STYLE

BEST COMPANY

# Bibliografia

| Índice Máximo Radiación UVB . Servicios Climáticos. (2025a, March).
https://climatologia.meteochile.gob.cl/application/mensual/indiceUvbMaximoMensual/330020/2025/3

Índice Radiación UVB; Máxima Diaria y Mensual y Anual . Servicios Climáticos. (2025b). https://climatologia.meteochile.gob.cl/application/anual/temperaturaMaximaAnual/330020/2025

ODS 3 salud y bienestar | pacto mundial onu. (n.d.-d).
https://www.pactomundial.org/ods/3-salud-y-bienestar/

UV index. Cancer Council Australia. (n.d.). https://www.cancer.org.au/cancer-information/causes-and-prevention/sun-safety/uv-index

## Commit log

2026-06-25 Implementación de servidor web que se actualiza cada 5 segundos
2026-06-25 Finalización de documentación de software en los README
2026-06-25 Corrección de parametros en README
2026-06-25 Correccion en la tabla UV
2026-06-25 Update library table format in FUENTES.md
    Corrección pequeña en la tabla de librerías utilizadas
2026-06-25 Mejora de descripciones en README.md
2026-06-25 Diagrama de flujos
